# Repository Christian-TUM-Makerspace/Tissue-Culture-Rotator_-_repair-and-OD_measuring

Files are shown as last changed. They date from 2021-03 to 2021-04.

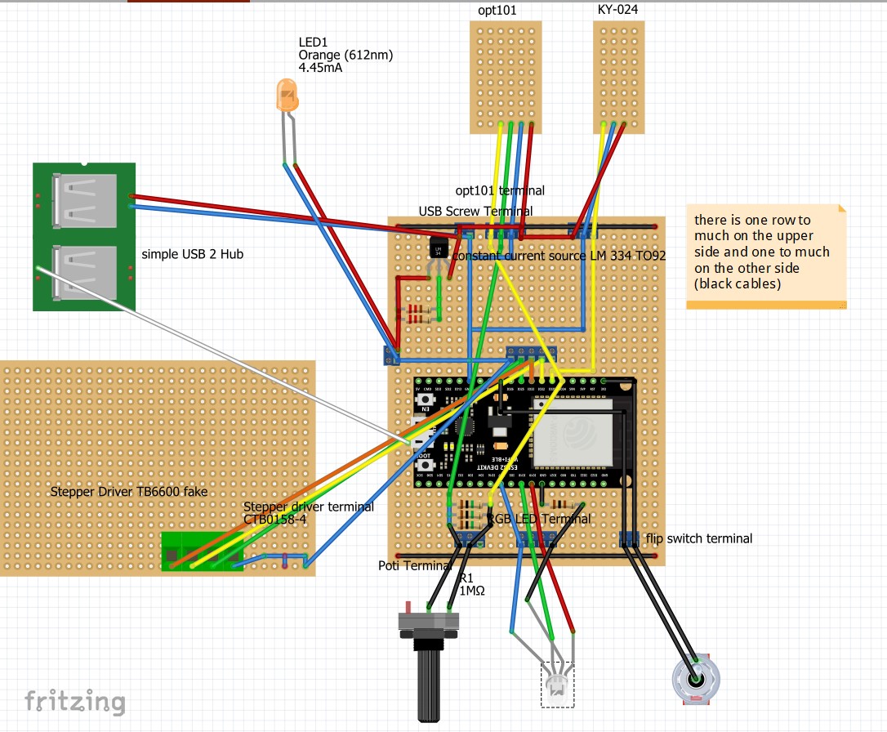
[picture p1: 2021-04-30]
electronics/pcb_board.jpg

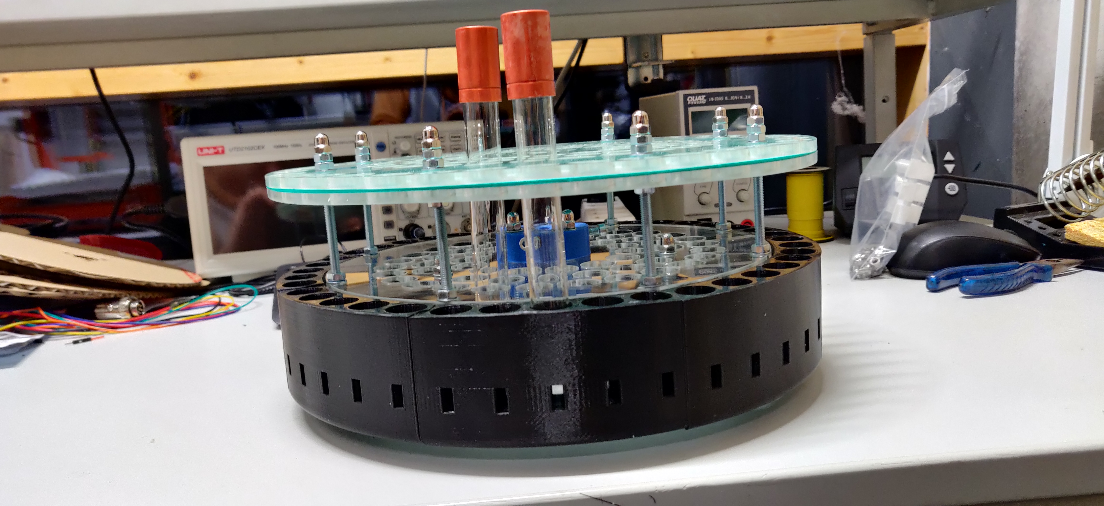
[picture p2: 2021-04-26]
images/Project 1.jpg

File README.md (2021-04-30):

# Tissue-Culture Rotator - repair and OD measuring

## Introduction

The main purpose of this project is to repair a New Brunswick Scientific TC-7. It is a makerspace student project. 

Only the old electric motor of Tissue-Culture Rotator is defective. It is replaced by a stepper motor. 

For monitoring microbiological growth, a sensor for the oclusion density (OD) of the liquid in the test tubes is added. The data is sent to a nearby PC.

The wheel is rebuilt from scratch in order to allow the OD measurements.

OD measurements will only work, if the slent is high (wenn der Apparat sehr schräg gestellt ist). With 5 ml in a test tube, you need to put something under the adjustment screw additionally (etwas unter die Einstellschraube legen, um den Apparat schräger zu stellen).

The project involves progamming, electronics, 3D CAD, 3D printing, Lasercutting and more.

Some specific programs, devices etc. used in this project: 
Arduino IDE, [FastAccelStepper library](https://github.com/gin66/FastAccelStepper), ESP32, Inventor, China Lasercutter.

## Status of the project (30. April 2021)

This is not a simple project to copy (yet). You need knowledge about the topics mentioned above.

Many problems could be solved and almost every aspect could be improved. Mostly it would not take much time. Maybe the project will be continued in winter semester 2021/22. 

## There are important READMEs in the subfolders

Do not overlook them.

## Tags

New Brunswick Scientific TC-7

Gewebekultur-Rotator

Tissue Culture Rotator

Rotating Mixer

Drum Rotator

## Lessons learned

Maybe it would have been easier to use an other type of motor.

In Inventor, set the dependencies carefully. Otherwise it can become almost impossible to change the model.

It is hard to find fitting timing belt pulleys. Especially if you work in Europe and repair a US device.

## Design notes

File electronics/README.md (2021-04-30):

# Some electronical parts (not complete)
- ESP32 (we used one with 38 pins, AZDelivery ESP32 Dev Kit C V4)
- simple USB Hub
- Potentiometer 1 MOhm for 6 mm hole
- LED 5mm, about 600 nm, small angle, bright (we use EVERLIGHT 383-2UYOC/S400-A7)
- 12 Volt power supply (if the stepper driver is set to 1.0 A, 12 Watt + Buffer)
- opt101 sensor with breakout board
- flip switch
- bright RGB LED that can be attattched somewhere visible (breakout board)
- TB6600 stepper driver (or fake)
- PCB Board 2,54 mm, 7 x 9 cm at least
- some resistors
- flip switch, ideally for a 12 mm hole

# Other annotations
- Leaded soldering tin was used.
- Avoid front USB busses.

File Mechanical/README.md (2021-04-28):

# Material list

## 1) Printed parts:

- 1x axis connection 1
- 1x axis connection 2
- 1x sensor segment
- 1x segment with magnets
- 7x segment without magnets 

Note: We used PLA as printingsmaterial

## 2) Lasered parts:

- 1x lowest plate (ACG)
- 1x middle plate (ACG)
- 2x upper plate (ACG)
- 1x upper plate (FR)

Note: We used 5mm acrylic glass (ACG) and 2mm foam rubber (FR)

## 3) Some screws and similiar parts (not complete)

- 2m M5 threaded rod
- M5 nuts
- M5 cap nuts
- M5 washers
- 3x M4x20 screws
- 3x M4 threaded insert

- 1x Neodym magnet, about 10 mm diameter

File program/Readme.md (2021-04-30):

# Program

## Flow Charts

Made with PapDesigner, download here
http://friedrich-folkmann.de/papdesigner/Hauptseite.html

## Arduino IDE

Enable Arduino IDE to work with an ESP32:

In Arduino IDE, File > Preferences > "Additional boards manager URLs:" copy and paste:
https://dl.espressif.com/dl/package_esp32_index.json

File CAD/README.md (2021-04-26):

We could not find out if it is allowed to publish CAD files from the student version of Autodesk Inventor. This is why we have no real 3D CAD files here.

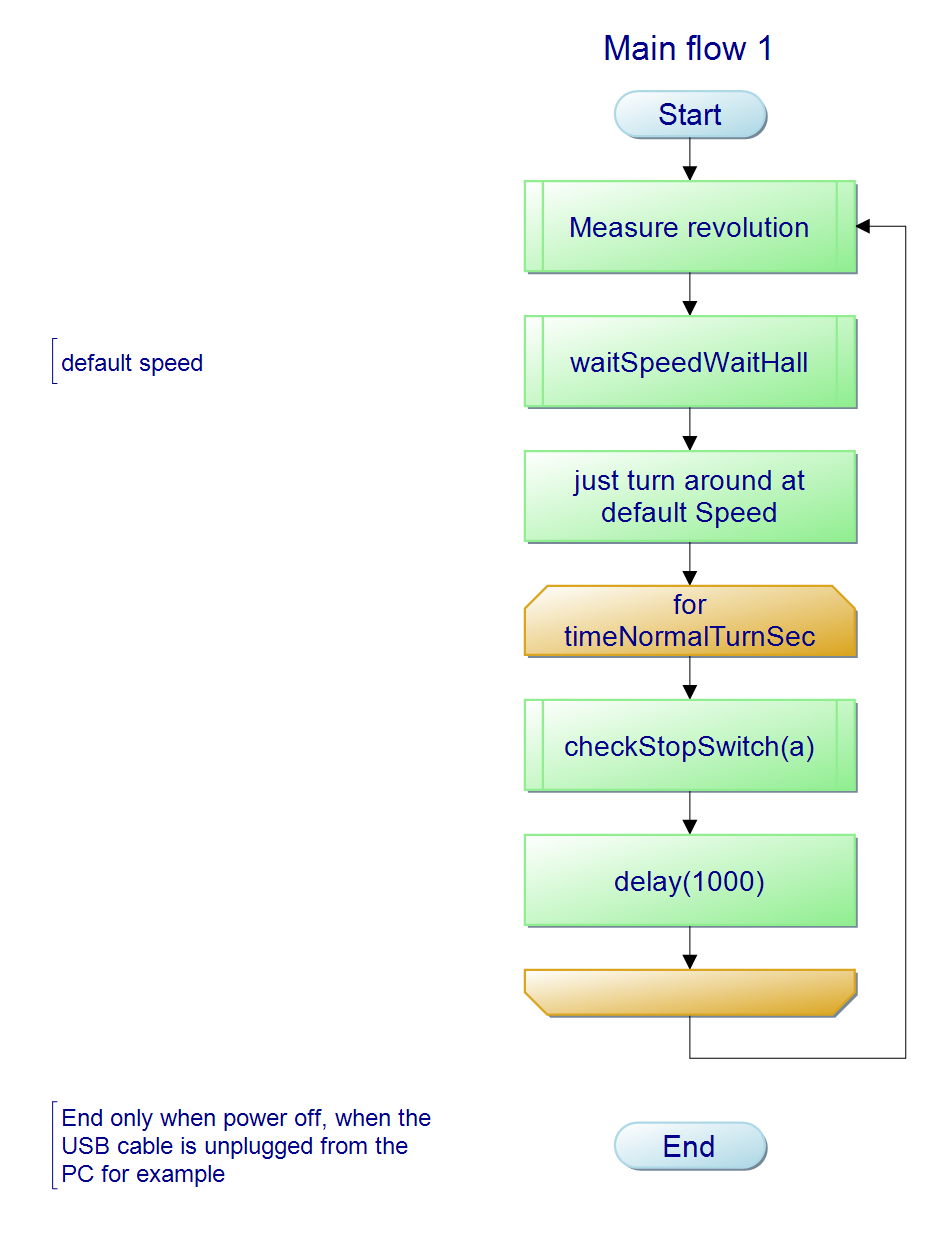
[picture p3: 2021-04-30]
program/images/Main flow 1.png

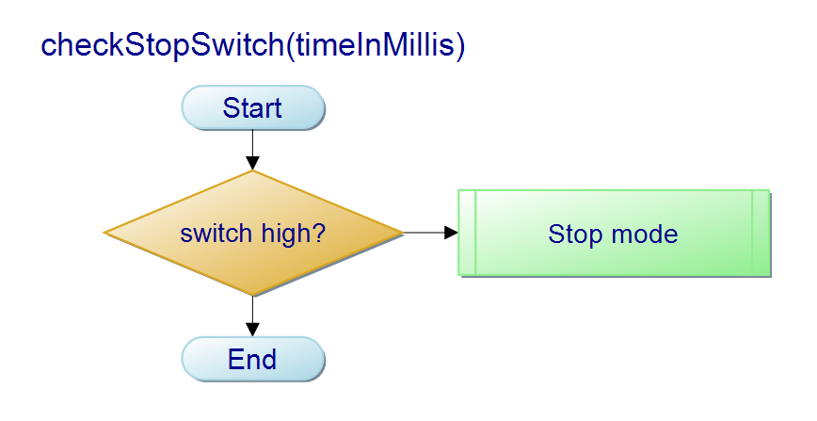
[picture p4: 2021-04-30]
program/images/checkStopSwitch(timeInMillis).png

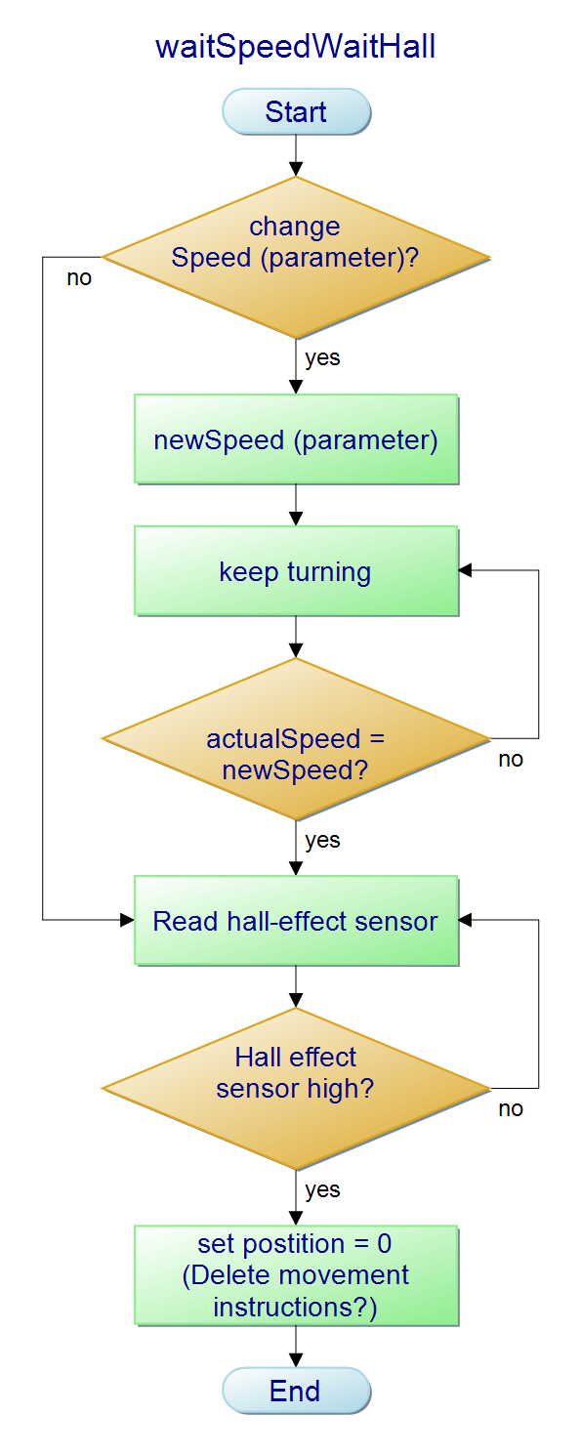
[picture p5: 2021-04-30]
program/images/waitSpeedWaitHall.png

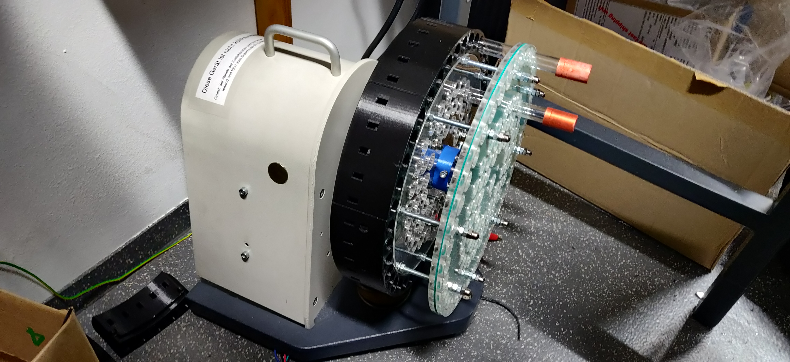
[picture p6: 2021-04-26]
images/Project 3.jpg

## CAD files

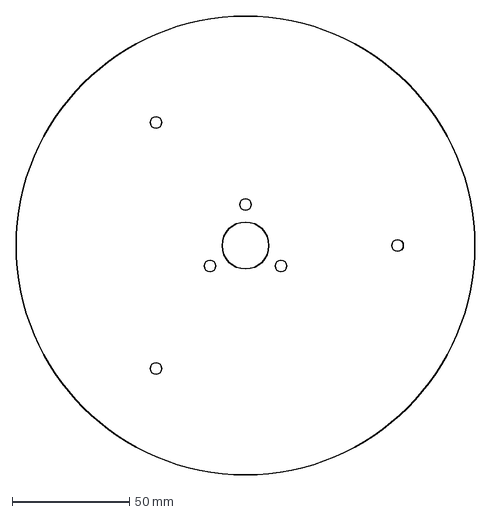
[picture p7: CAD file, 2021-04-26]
CAD/Lasercut/lowest plate.dxf
196.0 x 196.0 mm

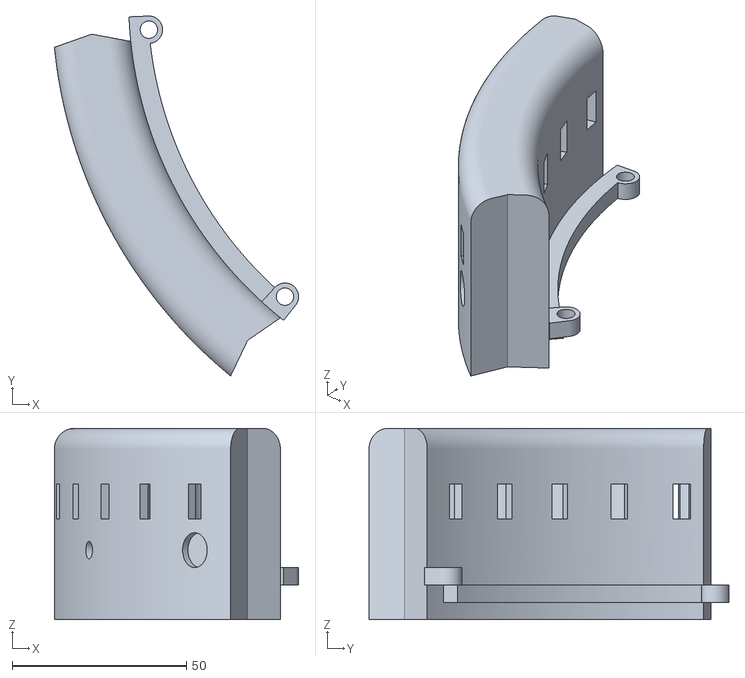
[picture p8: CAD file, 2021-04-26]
CAD/STL/segment with magnet.stl
70.2 x 103.4 x 55.0

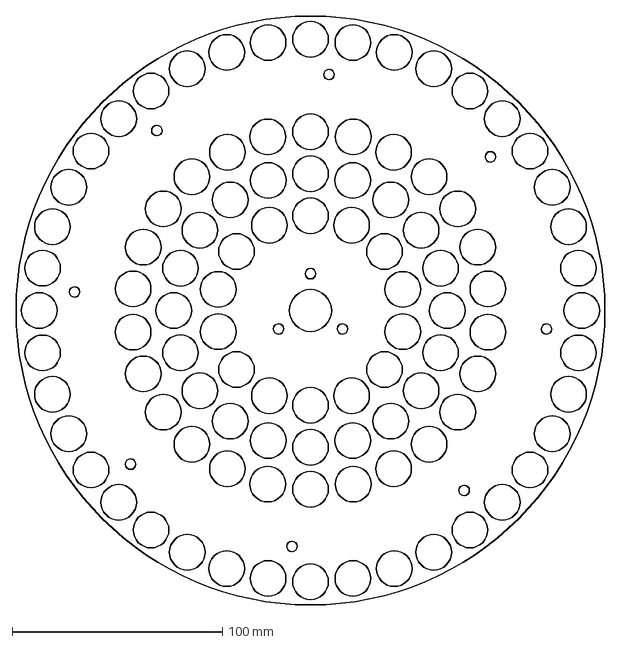
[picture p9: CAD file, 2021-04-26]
CAD/Lasercut/upper plate.dxf
280.0 x 280.0 mm

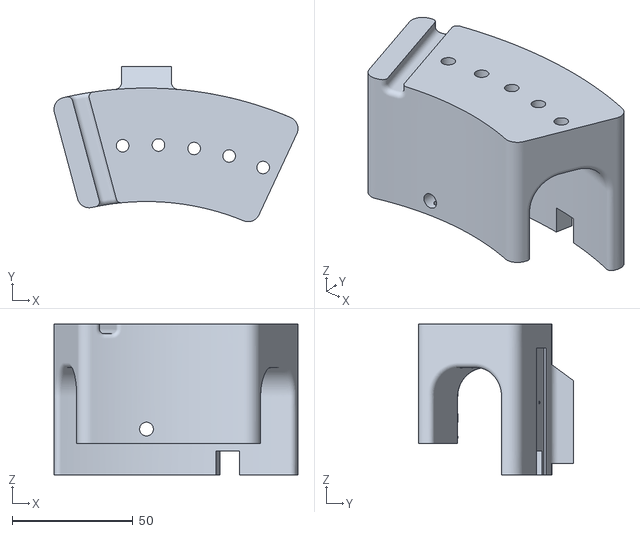
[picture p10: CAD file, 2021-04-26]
CAD/STL/sensor segment.stl
101.1 x 64.4 x 62.5

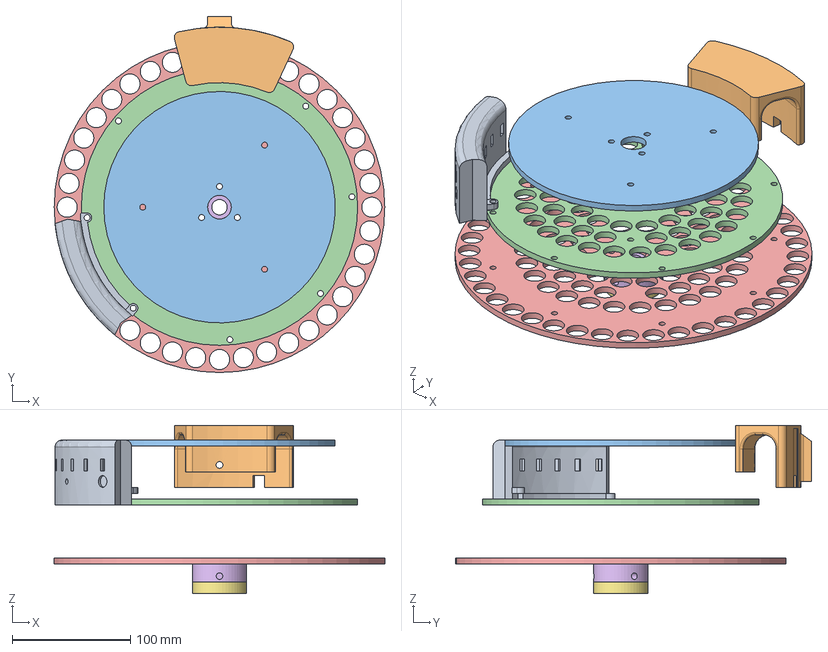
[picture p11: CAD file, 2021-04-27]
CAD/stp/Wheel_segments_PLA_acrylic_glas.stp
280.0 x 301.5 x 142.5 mm

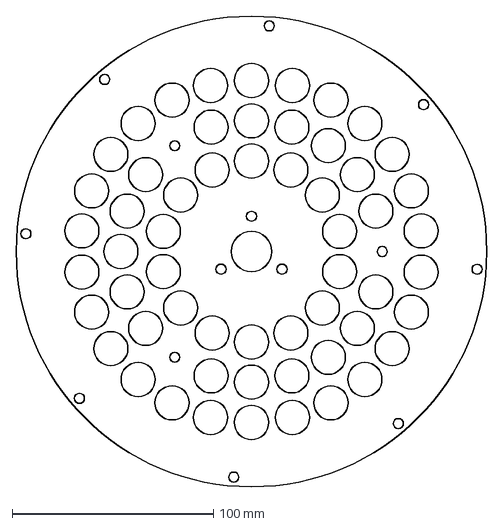
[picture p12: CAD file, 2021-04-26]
CAD/Lasercut/middle plate.dxf
234.0 x 234.0 mm

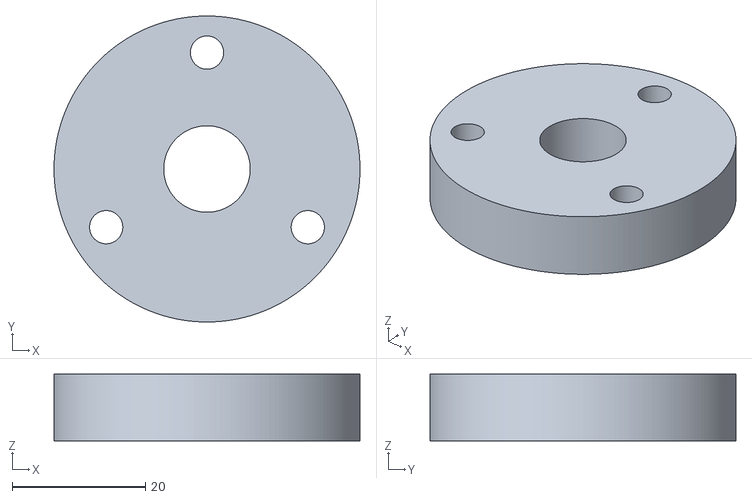
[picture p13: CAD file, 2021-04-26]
CAD/STL/axis connection 1.stl
46.0 x 46.0 x 10.0

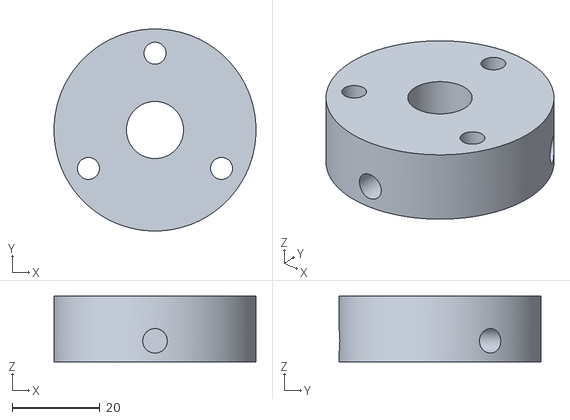
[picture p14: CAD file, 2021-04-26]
CAD/STL/axis connection 2.stl
46.0 x 46.0 x 15.0

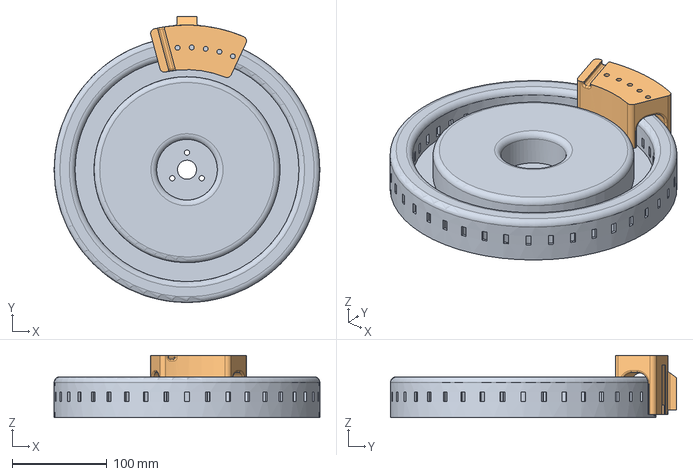
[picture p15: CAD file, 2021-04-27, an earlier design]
CAD/stp/Wheel_old.stp
280.0 x 301.5 x 65.5 mm

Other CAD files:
CAD/STL/segment without magnet.stl

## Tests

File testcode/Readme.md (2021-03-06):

Some small programms for the ESP32. Created while prototyping and while writing the main program. 
Not thorougly documented, cleared up or optimised, but with some comments and links. Some comments may be in German.

For reference and testing.

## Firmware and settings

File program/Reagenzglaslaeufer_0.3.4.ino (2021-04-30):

// Tissue-Culture-Rotator/Reagenzglasläufer

// Christian Schormair christian.schormair@tum.de
// Hans Ewigmann

//Tasks to be implemented are listed below the code

//functions must be declared before they can be called
void measurementRev();
void waitSpeedWaitHall (int speedMode, bool hallPosition);
void stopMode ();
void checkStopSwitch(int delayInMillis);

//how many seconds should the wheel turn between measurement turns? (through delay(), maybe takes some ms more)
//set here
int timeNormalTurnSec = 10;

//variables, constants, pins
  //basics
const unsigned short tubecount = 40;
  //array for measured values. first column [0] for raw data, second [1] for testing purposes (position for example)
int tubeValues[tubecount][2]={0};

  //Pins for sensors: opt101 and hall effekt sensor KY-024, flip switch
const int optPin= 34;
const int hallPin= 35;
const int switchPin = 27;

//Was not finished. Code is mostly written, but there was no time to find the problems.
//Calibration in stopMode(): The measured values of the opt101 should not reach the maximum (4095 for ESP32, see below)
//When the clear solution at the beginning is in the right position and the LED shines through, the value should be near 4095.
//Maybe print the lines above and tape them to the device.
//High resistance -> high amplification -> high value
  //Pins for the calibration LED (3 colors)
const int ledBlue = 17; //to low or not in the right position
const int ledGreen = 18; //Potentiometer is set correctly, if led never turns red when moving the wheel slowly around the right position.
const int ledRed = 19; //Potentiometer is set to high.
//RGB LED could also be used for showing the OD. Just an idea, no code here.
  //Lower limit for the calibration
const int lowerLimitCalibration = 3900;
  //lower Limit for calibration. below the calibration LED will turn blue.
  //ESP32 analogRead ranges between 0 and 4095 (12 bit). Change if you use a board with other values.
const int analogMax = 4095;

  //if the magnet is not found, set true. Try once again, then stop measurement.
bool magnetNotFound = false;
bool stopMeasurement = false;

//libraries
#include "FastAccelStepper.h"

//definitions for FastAccelStepper.h
  //Pins
const short dirPinStepper    =32; //not used, but maybe someone else wants to change the direction
const short enablePinStepper =25;
const short stepPinStepper   =33;
  //more for FastAccelStepper.h
FastAccelStepperEngine engine = FastAccelStepperEngine();
FastAccelStepper *stepper = NULL;

//For speed and position control
  //Set microstep mode at the stepper driver. 1, 2, 4, 8, 16, 32
  //Set respective value here:
const int stepsPerRevMotor = 6400; // = 200 * microstepmode. See table at stepper driver TB6600.
  //define ratio for timing belt pulleys here:
const float gearRatio = 50/25; //teeth on pulley on wheel divided through teeth pulley for motor
const float stepsPerRevWheel = stepsPerRevMotor * gearRatio;
  //Set speed here (in revolutions per second):
const float defaultRpsWheel  = 0.5; //not tested above 2. 
  //The following are own ("default") constants, the other speeds and accelerations are part of FastAccelStepper.h
  // Default speed in (micro-)steps/s   FastAccelStepper.h "allows up 200000 generated steps per second" on ESP32. Enough.
const float defaultSpeedInHz = stepsPerRevWheel * defaultRpsWheel; 
  //Set acceleration here:
const int defaultAcceleration = stepsPerRevMotor; // in steps/s²
  //Set speed for measure revolution here (in revolutions per MINUTE)
const float rpmMeasureWheel = 2; //0.5 seems to be around some kind of eigen frequency on our device
const float measurementSpeedInHz = stepsPerRevWheel * rpmMeasureWheel / 60;
  //positions on the wheel
    //steps per tube segment
const float stepsTubeSegm = stepsPerRevWheel/tubecount;
const int roundedStepsTubeSegm = round(stepsTubeSegm);//stepper can only make full (micro)steps, no comma steps

//to Serial.print the values in one print with "data" as keyword
String dataString = "data, ";
int measRevNr = 0;

//settings for hall sensor. change here, if the measurements are not made in the right positions.
  //offset for hall sensor. "how much to early the hall sensor reacts?" 
  //In percentage of a segment for one test tube.
const short offsetHallPercent = 15;
const int offsetHallSteps = stepsTubeSegm * offsetHallPercent / 100;
  //measured analog value of the hall sensor BELOW which the magnet is considered near
    //a hall sensor has a lower voltage when its near a magnet (in the right direction)
    //Use following test code if neccessary and choose a value some 100 below the maximum
    //https://github.com/Christian-TUM-Makerspace/Tissue-Culture-Rotator_-_repair-and-OD_measuring/blob/86767f8fad0253bf3ae0899edf4722ef4e440fe7/testcode/Hall_Sensor_KY-02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
const int valueMagnNear = 2300;

void setup() {
  Serial.begin(115200);

  //for flip switch for stopMode()

  pinMode(switchPin, INPUT_PULLDOWN);

  //for FastAccelStepper.h
  engine.init();
  stepper = engine.stepperConnectToPin(stepPinStepper);
  stepper->setDirectionPin(dirPinStepper);
  stepper->setAutoEnable(false);
  stepper->setEnablePin(enablePinStepper,false);
  stepper->setAcceleration(defaultAcceleration);
  stepper->setSpeedInHz(0);
  Serial.print("Default revolutions per second, wheel: ");
  Serial.println(defaultRpsWheel);
  Serial.print("defaultSpeedInHz: ");
  Serial.println(defaultSpeedInHz);
  Serial.print("Measurement, revolutions per MINUTE, wheel: ");
  Serial.println(rpmMeasureWheel);  
  Serial.print("defaultAcceleration: ");
  Serial.println(defaultAcceleration);  
  Serial.print("measurementSpeedInHz: ");
  Serial.println(measurementSpeedInHz);  
  Serial.print("roundedStepsTubeSegm: ");
  Serial.println(roundedStepsTubeSegm);  
  Serial.print(": ");
  Serial.println();  

  pinMode(optPin, INPUT);
  pinMode(hallPin, INPUT);
  pinMode(ledBlue, OUTPUT);
  digitalWrite(ledBlue, LOW);//somehow it shines a little  
  pinMode(ledGreen, OUTPUT);
  pinMode(ledRed, OUTPUT);
}

//No continious check of the flip switch. Insert function between all steps that take more than a second or so.
void checkStopSwitch(int delayInMillis = 0){
  if (digitalRead(switchPin)== HIGH){
    stopMode ();    
  } 
  delay(delayInMillis);
}

//Does not work
//Set the motor free to insert the test tubes and calibrate
//Documentation for the calibration in the header
//Can not be called if Speed is set 0 otherwise
void stopMode (){
  waitSpeedWaitHall(0,false);
  stepper->setEnablePin(enablePinStepper,true);
  while (digitalRead(switchPin) == HIGH) {
    Serial.println("In loop for LED and switch pin");    
    int stopModeOpt = analogRead(optPin);
    if (stopModeOpt == analogMax){
      digitalWrite(ledBlue, LOW);
      digitalWrite(ledGreen, LOW);
      digitalWrite(ledRed, HIGH);
      delay(200); // to make it visible
    }
    else if (lowerLimitCalibration < stopModeOpt  && stopModeOpt < analogMax){
      digitalWrite(ledBlue, LOW);
      digitalWrite(ledGreen, HIGH);
      digitalWrite(ledRed, LOW);
    }
    else if (lowerLimitCalibration > stopModeOpt){
      digitalWrite(ledBlue, HIGH);
      digitalWrite(ledGreen, LOW);
      digitalWrite(ledRed, LOW);
    }
  }
  stepper->setEnablePin(enablePinStepper,false);
  digitalWrite(ledBlue, LOW);
  digitalWrite(ledGreen, LOW);
  digitalWrite(ledRed, LOW);
  Serial.println("End of stopMode()");  
}

void measurementRev(){
  //for testing:
  //int countValues = 0;
  
  //Bring wheel to measure speed
  if (stepper->getCurrentSpeedInMilliHz()/1000 - measurementSpeedInHz > 10){
    waitSpeedWaitHall(2,true);
  }
  //zero the array
  memset(tubeValues, 0, sizeof tubeValues);

  int optValTemp = 0;

  // reset String for every measurement revolution
  dataString = "data, ";
  // Number of the current measurement revolution
  dataString = dataString + measRevNr + ", ";
  
  //measure one tube after another
  for (short i=0; i < tubecount; i++){
    checkStopSwitch();
    int startPos = (i+0.25) * stepsTubeSegm;
    int endPos = (i+0.75) * stepsTubeSegm;
    //measure repeatedly while opt101 is near tube, keep the maximum value
    int optValTemp = 0;
    //wait until tube is near opt101
    while(stepper->getCurrentPosition() < startPos){
    delay(1);

    }
    while (stepper->getCurrentPosition()< endPos){
      //countValues = countValues + 1;
      optValTemp = analogRead(optPin);
      if (optValTemp > tubeValues[i][0]){
        tubeValues[i][0] = optValTemp;
        //for testing, if the postions are right:
        //tubeValues[i][1] = stepper->getCurrentPosition();
        
        //for OD
        //tubeValues[i][1] = insert formula for OD here. OD = f(tubeValues[i][0]);
      }
    }
    dataString = dataString + tubeValues[i][0] + ", ";
    Serial.println(tubeValues[i][0]);

  }
  //check if the revolution ran normal
  int posTemp = stepper->getCurrentPosition();
  while (posTemp + 0.25*stepsTubeSegm > stepper->getCurrentPosition()){
    if (analogRead(hallPin) > valueMagnNear){
      Serial.println("measurement revolution successfull ");
      Serial.println(dataString);
      magnetNotFound = false;
      return;
    }
  }
  //stop the masurement if the magnet is not found two times in sequence
  if (magnetNotFound == false){
    magnetNotFound = true;
  }
  else {
    stopMeasurement = true;
    Serial.println("Magnet was not found two times in sequence. Stopping measurement.");
  }  

  //
  // function: send data
  //
}

//Set new speed, wait until it is reached, if hallPosition = true: wait for magnet and set position to 0 there (or near zero, with offset)
void waitSpeedWaitHall (int speedMode = 1, bool hallPosition = true){ //Speed Modes: 0...stop, 1...keep speed, 2...measurementSpeed, 3...defaultSpeed, 4...for testing
  stepper->setEnablePin(enablePinStepper,false);
  
  if(speedMode==3){
    stepper->setSpeedInHz(defaultSpeedInHz);
    stepper->runForward();
    Serial.println("Speed mode 3: defaultSpeed");
  }
  else if(speedMode==2){  
    stepper->setSpeedInHz(measurementSpeedInHz);
    stepper->runForward();
    Serial.println("Speed mode 2: measurementSpeed");
  }
  else if(speedMode==1){
    stepper->setSpeedInHz(stepper->getSpeedInMilliHz()*1000);
    stepper->runForward();
  }
  else if(speedMode==0){
    stepper->keepRunning();
    stepper->stopMove();
    stepper->setSpeedInHz(0);
    Serial.println("Speed mode 0: stop");
  }
  else if(speedMode==4){
    Serial.println("Speedmode 4: test");
    stepper->setAcceleration(100);
    stepper->setSpeedInHz(500);
    stepper->move(100);
    delay(5000);
  }
  else{
    Serial.println("Error: Wrong number for speedMode");
    Serial.println("Speed Modes: 0...stop, 1...keep speed, 2...measurementSpeed, 3...defaultSpeed, 4...for testing");
  }
  while (abs(stepper->getSpeedInMilliHz() - stepper->getCurrentSpeedInMilliHz())> 10){//somehow it never gets the same for higher speeds
    Serial.print("CurrentSpeedInMilliHz = ");    
    Serial.println(stepper->getCurrentSpeedInMilliHz());
    Serial.print("Set SpeedInMilliHz = ");    
    Serial.println(stepper->getSpeedInMilliHz());
    delay(100);
  }
  //Set the position to zero or a corrected value (= minus offset) around zero
    //Ignores the time for acceleration. Should be ok for measuring. Keep in mind for other uses.
  if (hallPosition == true){
    while (analogRead(hallPin) > valueMagnNear){
    }
    Serial.println("hallPin near");
    //a workaround: With the ESP32, FastAccelStepper.h can not set the current position when moving.
      //see: https://github.com/gin66/FastAccelStepper/blob/258ffb42d34a971ff1f193b82b1a1abefbc27229/src/FastAccelStepper.h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
    stepper->keepRunning();
    stepper->stopMove();
    delay(100);
    stepper->setCurrentPosition(-offsetHallSteps);  
    int pos = stepper->getCurrentPosition();  
    stepper->runForward();
  }
}

void loop(){
/*  int buttonPressed = digitalRead(switchPin);
  if (digitalRead(switchPin) == HIGH){
    Serial.println("switch is on");
  } 
  else {
    Serial.println("switch is off");
  }
  delay(100);
*/
  waitSpeedWaitHall(3,false);
  for (int i = 0; i < timeNormalTurnSec;i++){
    delay(1000);
    //checkStopSwitch(1000);
  }
  if (stopMeasurement == false){
    measurementRev();
    waitSpeedWaitHall(3,false);
    //timeNormalTurnSec = 1;//>=1
    for (int i = 0; i < timeNormalTurnSec;i++){
      delay(1000);
      //checkStopSwitch(1000);
    }

  }
  
  Serial.println(analogRead(optPin));
  delay(100);
}



/////////////////////////
//Tasks to be implemented:
/////////////////////////

//Multitasking was planned, but then an almost pure serial approach was used. Even for the stopSwitch.
//Information about multitasking on ESP32:
  //https://savjee.be/2020/01/multitasking-esp32-arduino-freertos/
  //https://randomnerdtutorials.com/esp32-dual-core-arduino-ide/
  //https://www.instructables.com/ESP32-With-Arduino-IDE-Multi-Core-Programming/
  //https://docs.espressif.com/projects/esp-idf/en/latest/esp32/api-reference/system/freertos.html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

  // "at the same time, all the time":
    //drive stepper motor via PWM FastAccelStepper.h  https://github.com/gin66/FastAccelStepper (https://github.com/pkerspe/ESP-FlexyStepper)
    //read opt101
    //read hall sensor (only when its likely that the magnet is near)
    //read stopSwitch via interrupt



// other tasks:
  //accelerate stepper motor
  //processing the data
    //find maximums
    //manage the values for one rotation
  //send data to PC
  //correct position if neccessary
  //send ENA (to make the stepper motor loose), stop data processing meanwhile
  //maybe turn on/off a LED or use a display that shows, if the maximum of the the range of the opt101 is reached 
                                    //(to adjust sensitivity of the sensor through potentiometer if neccessary)

// Hard coded "variables". Change here in the code and load up the new program to the ESP32. 
// Avoids the need for a display, buttons and additional programming for that. We will see if that is enough.
// Hardcoded "variables":
  //speed of the stepper motor

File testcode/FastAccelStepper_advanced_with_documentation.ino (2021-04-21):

//https://github.com/gin66/FastAccelStepper

//modified example with version 0.23.0

//documentation for usage:
//https://github.com/gin66/FastAccelStepper/blob/master/src/FastAccelStepper.h
//permalink to the version used here:
//https://github.com/gin66/FastAccelStepper/blob/2e0bba84d3dead4e6b8de964defb1c3f78daa21f/src/FastAccelStepper.h
//There is much text and it is hard to find the basics there.
//Some annotations from there were copied to this sketch with own annotations added.

//This library was chosen because it uses PWM on the ESP32, which should be much much less CPU-intensive.

/*  

  // about enable and disable
  // FastAccelStepper.h   line 51 ff
  https://github.com/gin66/FastAccelStepper/blob/2e0bba84d3dead4e6b8de964defb1c3f78daa21f/src/FastAccelStepper.h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

  
  // maybe it is better to turn auto_enable off
  // maybe that avoids problems with many operations "at the same time"
  // FastAccelStepper.h   line 69 - 90
  bool auto_enable = false;
  stepper->setAutoEnable(false);

  
  // Retrieve the current position of the stepper
  int32_t getCurrentPosition();

  // Set the current position of the stepper - either in standstill or while moving
      //    for esp32: the implementation uses getCurrentPosition(), which does not
      //               consider the steps of the current command
      //               => recommend to use only in standstill
  // FastAccelStepper.h   line 101 ff
      void setCurrentPosition(int32_t new_pos);
        

  // For stepper movement control by FastAccelStepper's ramp generator
  //
  // setSpeedInUs expects as parameter the minimum time between two steps.
  // If for example 5 steps/s shall be the maximum speed of the stepper,
  // then t = 0.2 s/steps = 200000 us/step, so call
  //      setSpeedInUs(200000);
  // FastAccelStepper.h   line 114 ff
  // more details in FastAccelStepper.h

  // setSpeedInHz() allows to set the stepper speed as step frequency in Hertz.
  // This means steps/s.
  //Line 147 ff

  
  // set Acceleration expects as parameter the change of speed
  // as step/s².
  // If for example the speed should ramp up from 0 to 10000 steps/s within
  // 10s, then the acceleration is 10000 steps/s / 10s = 1000 steps/s²
     setAcceleration()
  // Line 159 ff
  // more details in FastAccelStepper.h

  
  // This function applies new values for speed/acceleration.
  // This is convenient especially, if the stepper is set to continuous running.
  void applySpeedAcceleration();
  // Line 181 ff

  
  // start/move the stepper for (move) steps or to an absolute position.
  //
  // If the stepper is already running, then the current running move will be
  // updated together with any updated values of acceleration/speed. The move is
  // relative to the target position of any ongoing move ! If the new
  // move/moveTo for an ongoing command would reverse the direction, then the
  // command is silently ignored.
  int8_t move(int32_t move);
  int8_t moveTo(int32_t position);
  // more about feedback in FastAccelStepper.h
  // Line: https://github.com/gin66/FastAccelStepper/blob/2e0bba84d3dead4e6b8de964defb1c3f78daa21f/src/FastAccelStepper.h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


  // There are 2 ways to run the motor continiously:
  https://github.com/gin66/FastAccelStepper/blob/2e0bba84d3dead4e6b8de964defb1c3f78daa21f/src/FastAccelStepper.h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
  
  // This command flags the stepper to keep run continuously into current
  // direction. It can be stopped by stopMove.
  // Be aware, if the motor is currently decelerating towards reversed
  // direction, then keepRunning() will speed up again and not finish direction
  // reversal first.
  void keepRunning();
  bool isRunningContinuously() { return _rg.isRunningContinuously(); }

  // This command just let the motor run continuously in one direction.
  // If the motor is running in the opposite direction, it will reverse
  // return value as with move/moveTo
  int8_t runForward() { return _rg.startRun(true); }
  int8_t runBackward() { return _rg.startRun(false); }


  // There are 2 ways to stop movement
  https://github.com/gin66/FastAccelStepper/blob/2e0bba84d3dead4e6b8de964defb1c3f78daa21f/src/FastAccelStepper.h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

  // stop the running stepper as fast as possible with deceleration
  // This only sets a flag and can be called from an interrupt !
  void stopMove();
  bool isStopping() { return _rg.isStopping(); }

  // stop the running stepper immediately and set new_pos as new position
  // This can be called from an interrupt !
  void forceStopAndNewPosition(uint32_t new_pos);
  
  //Do not get confused:
  //getCurrentSpeedInMilliHz() is calculated by: getCurrentSpeedInMilliHz() = speed in Hertz * 1000
  //in other words: how many steps happen in 1000 seconds
  //or: Speed in Hertz = getCurrentSpeedInMilliHz() / 1000
*/

//FastAccelStepper
#include "FastAccelStepper.h"

#define dirPinStepper    32
#define enablePinStepper 25
#define stepPinStepper   33


//Set microstep mode at the stepper driver. 1, 2 , 4, 8, 16, 32
//Set respective value here:
#define pulsesPerRevMotor  1600 // = 200 * microstepmode. See table at stepper driver TB6600.
//define timing belt pulleys here:
#define gearRatio 50/25 //teeth on pulley on wheel divided through teeth pulley for motor
#define pulsesPerRevWheel pulsesPerRevMotor * gearRatio
//Set speed here:
#define revPerSecondWheel  2
//The following are own ("default") constants, the other speeds and accelerations are part of FastAccelStepper.h
#define defaultSpeedInHz pulsesPerRevWheel * revPerSecondWheel // in (micro-)steps/s
//Set acceleration here:
#define defaultAcceleration  pulsesPerRevMotor // in steps/s²

FastAccelStepperEngine engine = FastAccelStepperEngine();
FastAccelStepper *stepper = NULL;

void setup() {
  Serial.begin(115200);
  
  engine.init();
  stepper = engine.stepperConnectToPin(stepPinStepper);

  stepper->setDirectionPin(dirPinStepper);
  stepper->setEnablePin(enablePinStepper);
  stepper->setAutoEnable(false);
  stepper->enableOutputs();
  
  stepper->setSpeedInUs(1000);  // the parameter is us/step !!!
  stepper->setAcceleration(1000);
}

void loop() {
  //Serial.print(stepper->getCurrentPosition());
  //Serial.print("   ");
  stepper->runForward();
  delay(10000);
  //Serial.println(stepper->getCurrentPosition());
  stepper->stopMove();
  Serial.println(stepper->getCurrentSpeedInMilliHz()*1000);
  delay(10000);
  Serial.println(stepper->getCurrentSpeedInMilliHz()*1000);
  delay(2000);  
}

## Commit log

2021-03-05 Add files via upload
    A simple program made for testing stepper motor and sensors, translated from German to English and cleaned up. Deleted simple PWM control for stepper motor. Based on OPT101_und_Schrittmotor_und_Hall-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
2021-03-05 Added programs and devices
2021-03-07 Make vTaskDelay( ) run with Serial.println( ) for testing
2021-03-08 Add Flowchart to test images in Readme
2021-04-13 removed size of the printer bed
2021-04-13 deleted comment for library not used
    //read flip switch or button for ENA, to make the stepper motor loose
    this line: //(Use, but please note the last comment at: ESP_FlexyStepper.h -> Example3_EmercencySwitch)
    [Reagenzglaslaeufer_0.2.1.ino]
2021-04-14 added gear ratio
2021-04-20 replace #define by const int
    [Reagenzglaslaeufer_0.2.3.ino]
2021-04-20 Add waitSpeedWaitHall() + change some data types and names
    + add some speed related constants + some small changes and corrections
    [Reagenzglaslaeufer_0.2.4.ino]
2021-04-20 correct formulas with Hz and MilliHz
    [Reagenzglaslaeufer_0.2.4.ino]
2021-04-24 Stepper and measurements connected, corrections neccessary
    But it works!
    [Reagenzglaslaeufer_0.3.0.ino]
2021-04-25 Corrected tubeCount and added some print(variable) for testing
    [Reagenzglaslaeufer_0.3.1.ino]
2021-04-26 Changed hall Sensor to analogRead
    digitalRead is hard to handle
2021-04-28 Deleted interrupt
2021-04-29 Sorry, German
    [Messwerte Optik.xlsx]
